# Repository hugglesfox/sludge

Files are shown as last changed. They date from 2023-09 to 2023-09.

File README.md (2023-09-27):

# Sludge

Sludge is a hardware platform which is compatible with
[SlimeVR](https://slimevr.dev) firmware. Sludge is designed to be as
featureless and cost down as reasonable to provide a cheaper and updated
alternative to the official SlimeVR hardware.

## Features

- ESP32-C3 + Bosch BMI160
- Powered by a swappable AA battery
- Firmware flashing and hardware debugging over USB

## Does not feature

- Battery charging
- Expansion modules (e.g. for easier foot rotation tracking)

## TODO

- [X] General electrical design
- [ ] Clean up silk screen
- [ ] Switch to USB-C
- [ ] Physical design (straps, casing, etc.)
- [ ] Real world testing

## Licensing

Sludge (c) by Hayley Hughes and Contributors

Sludge is licensed under a
Creative Commons Attribution-ShareAlike 4.0 International License.

You should have received a copy of the license along with this
work. If not, see <http://creativecommons.org/licenses/by-sa/4.0/>.

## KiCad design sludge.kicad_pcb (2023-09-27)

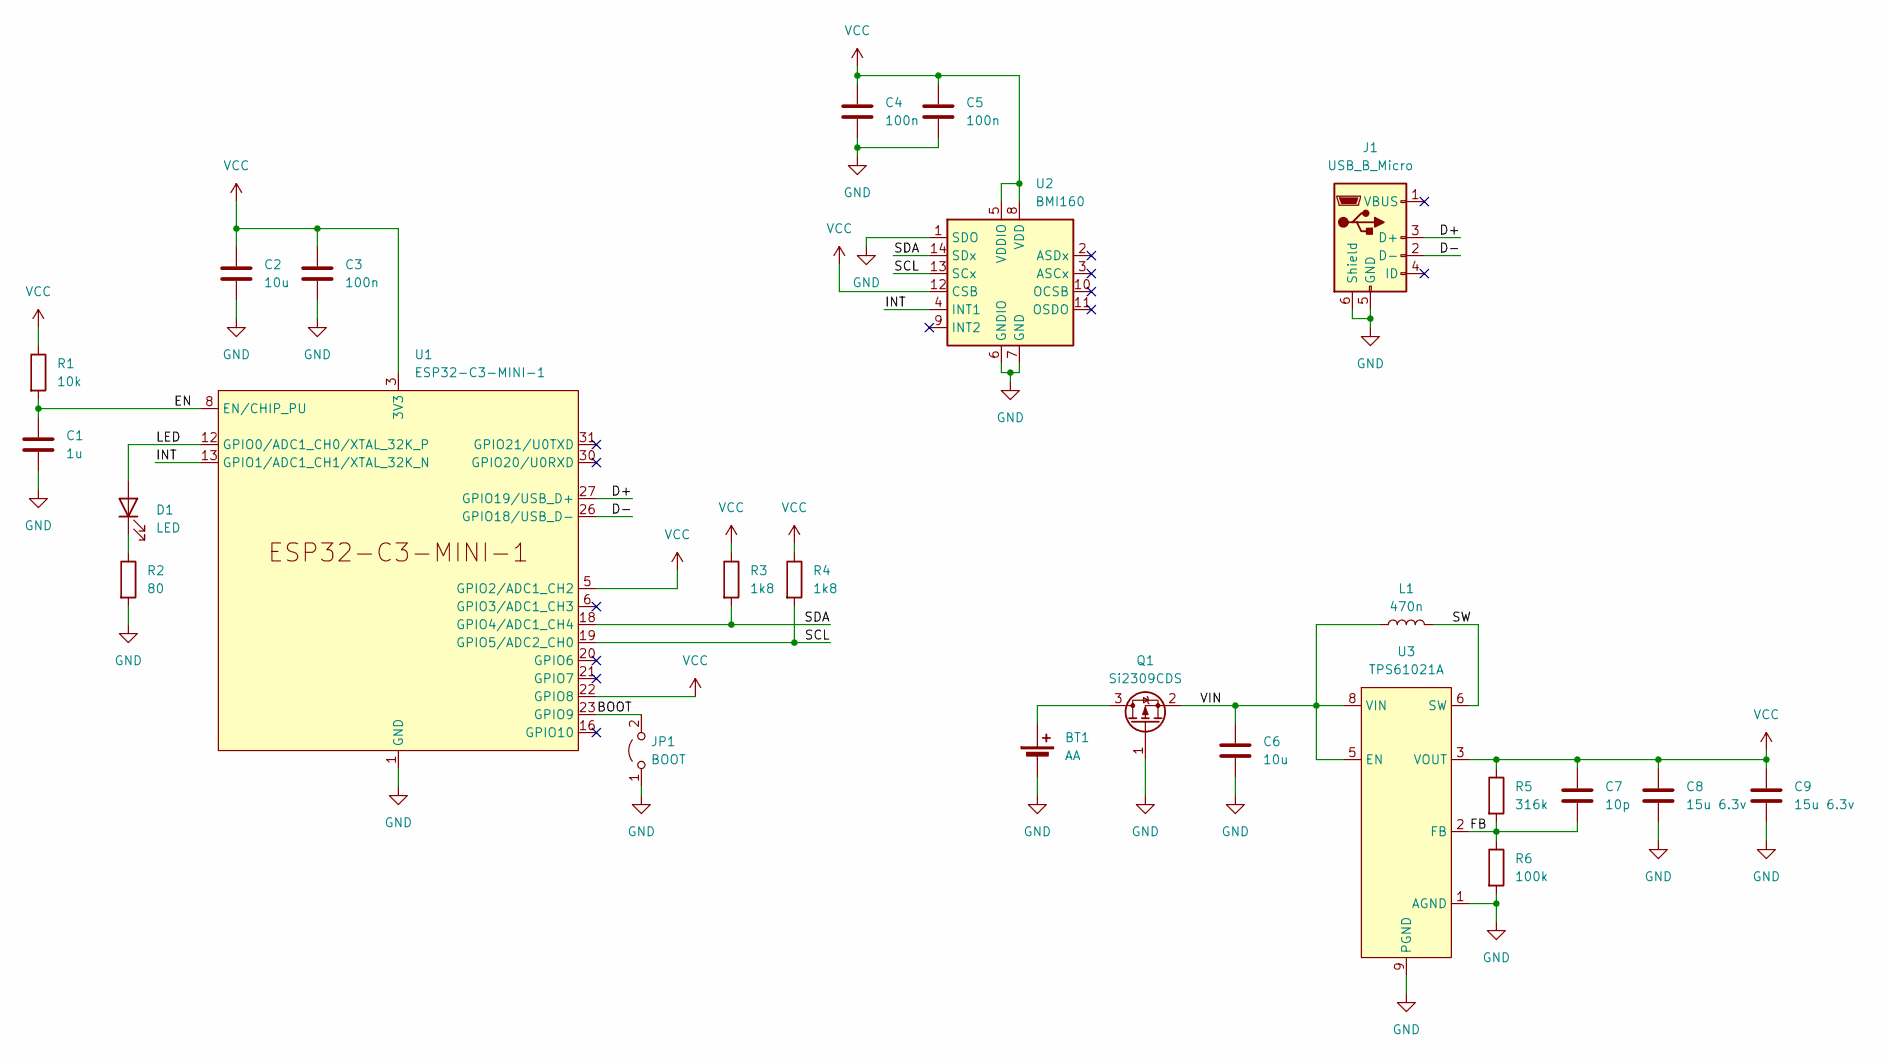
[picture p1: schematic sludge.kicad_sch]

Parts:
BT1: AA; BatteryHolder_Keystone_2460_1xAA
C1: 1u; C_0402_1005Metric
C2, C6: 10u; C_0402_1005Metric
C3, C4, C5: 100n; C_0402_1005Metric
C7: 10p; C_0402_1005Metric
C8, C9: 15u 6.3v; C_0603_1608Metric; JLCPCB Part # C445715
D1: LED; LED_1206_3216Metric; JLCPCB Part # C2764893
J1: USB_B_Micro; USB_Micro-B_Amphenol_10104110_Horizontal; JLCPCB Part # C2931352
JP1: BOOT; SolderJumper-2_P1.3mm_Open_TrianglePad1.0x1.5mm
L1: 470n; L_1008_2520Metric; JLCPCB Part # C237552
Q1: Si2309CDS; SOT-23; JLCPCB Part # C10493
R1: 10k; R_0402_1005Metric
R2: 80; R_0402_1005Metric
R3, R4: 1k8; R_0402_1005Metric
R5: 316k; R_0402_1005Metric
R6: 100k; R_0402_1005Metric
U1: ESP32-C3-MINI-1; JLCPCB Part # C5290152
U2: BMI160; Bosch_LGA-14_3x2.5mm_P0.5mm; JLCPCB Part # C94021
U3: TPS61021A; WSON-8-1EP_2x2mm_P0.5mm_EP0.9x1.6mm_ThermalVias; JLCPCB Part # C193037

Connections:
/BOOT: JP1.2 (B), U1.23 (GPIO9)
/D+: J1.3 (D+), U1.27 (GPIO19/USB_D+)
/D-: J1.2 (D-), U1.26 (GPIO18/USB_D-)
/EN: C1.1, R1.2, U1.8 (EN/CHIP_PU)
/FB: C7.2, R5.2, R6.1, U3.2 (FB)
/INT: U1.13 (GPIO1/ADC1_CH1/XTAL_32K_N), U2.4 (INT1)
/LED: D1.2 (A), U1.12 (GPIO0/ADC1_CH0/XTAL_32K_P)
/SCL: R4.2, U1.19 (GPIO5/ADC2_CH0), U2.13 (SCx)
/SDA: R3.2, U1.18 (GPIO4/ADC1_CH4), U2.14 (SDx)
/SW: L1.2, U3.6 (SW), U3.7 (SW)
/VIN: C6.1, L1.1, Q1.2 (S), U3.5 (EN), U3.8 (VIN)
GND: BT1.2 (-), C1.2, C2.2, C3.2, C4.2, C5.2, C6.2, C8.2, C9.2, J1.5 (GND), J1.6 (Shield), JP1.1 (A), Q1.1 (G), R2.2, R6.2, U1.1 (GND), U1.2 (GND), U1.11 (GND), U1.14 (GND), U1.36 (GND), U1.37 (GND), U1.38 (GND), U1.39 (GND), U1.40 (GND), U1.41 (GND), U1.42 (GND), U1.43 (GND), U1.44 (GND), U1.45 (GND), U1.46 (GND), U1.47 (GND), U1.48 (GND), U1.49 (GND), U1.50 (GND), U1.51 (GND), U1.52 (GND), U1.53 (GND), U2.1 (SDO), U2.6 (GNDIO), U2.7 (GND), U3.1 (AGND), U3.9 (PGND)
unnamed: BT1.1 (+), Q1.3 (D)
unnamed: D1.1 (K), R2.1
VCC: C2.1, C3.1, C4.1, C5.1, C7.1, C8.1, C9.1, R1.1, R3.1, R4.1, R5.1, U1.3 (3V3), U1.5 (GPIO2/ADC1_CH2), U1.22 (GPIO8), U2.5 (VDDIO), U2.8 (VDD), U2.12 (CSB), U3.3 (VOUT), U3.4 (VOUT)

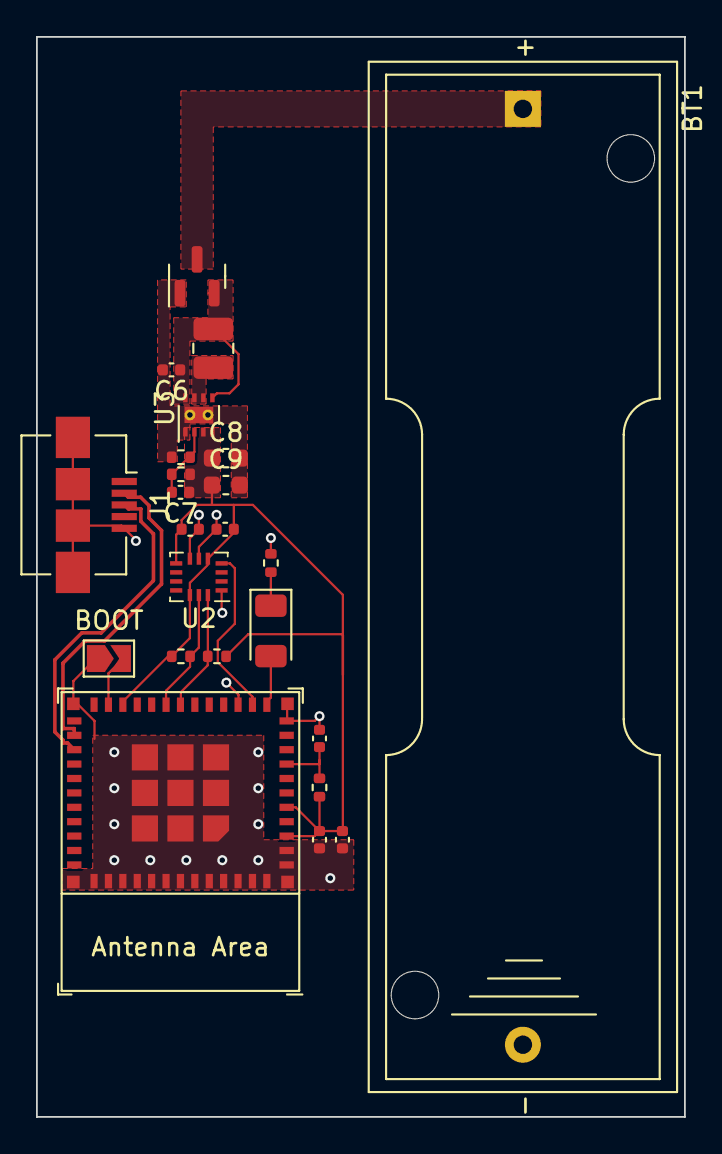
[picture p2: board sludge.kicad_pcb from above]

Board: 2 copper layers, 36.0 x 60.0 mm, 24 parts (0 on the bottom side), 15 nets.
